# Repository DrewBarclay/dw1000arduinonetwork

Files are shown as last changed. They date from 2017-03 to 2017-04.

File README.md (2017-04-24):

# dw1000arduinonetwork
For our computer engineering capstone project. Takes a number of DW1000s hooked up to Arduinos and has them transmit their range information to each other and to serial interfaces. For use with our other projects.

Code is intended to run on an Arduino Pro Mini 3.3V. See https://github.com/thotro/arduino-dw1000 for the core code used, as well as the final report at https://github.com/DrewBarclay/ARLocationTracking for more information.

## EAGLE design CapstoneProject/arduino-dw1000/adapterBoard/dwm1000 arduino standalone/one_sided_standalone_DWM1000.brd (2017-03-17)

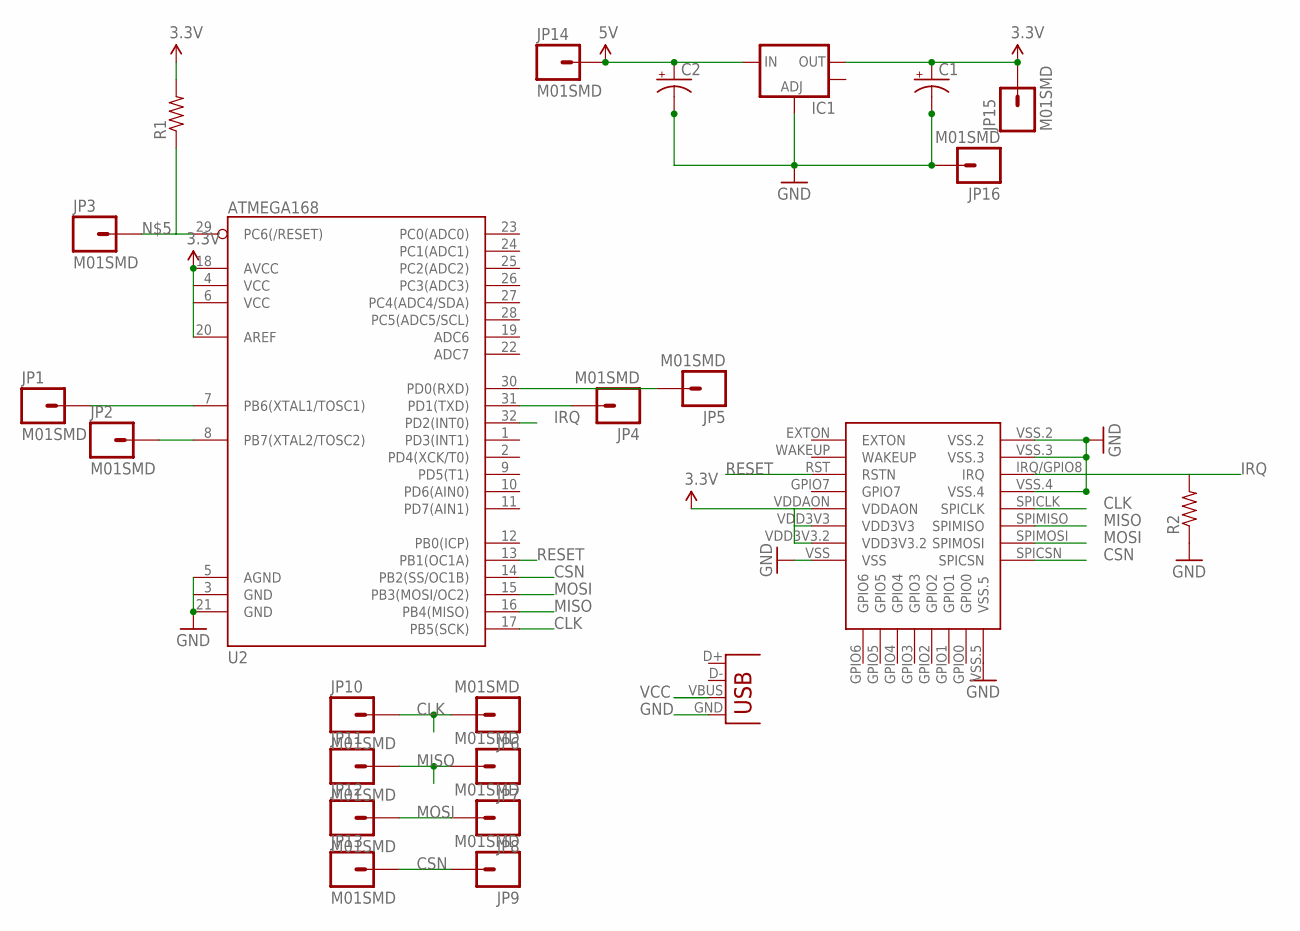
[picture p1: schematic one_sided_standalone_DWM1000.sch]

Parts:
C1, C2: CAP_POL3528-KIT; EIA3528-KIT
IC1: V_REG_LM1117SOT223; SOT223
JP1, JP2, JP3, JP4, JP5, JP6, JP7, JP8, JP9, JP10, JP11, JP12, JP13, JP14, JP15, JP16: M01SMD; LUXEON-PAD
R1, R2: RESISTOR0805-RES; 0805
U2: ATMEGA168; TQFP32-08
U$1: DWM1000
X1: USB-MICROB

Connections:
CLK: JP6.P$1, JP10.P$1, U2.17 (PB5(SCK)), U$1.SPICLK
CSN: JP9.P$1, JP13.P$1, U2.14 (PB2(SS/OC1B)), U$1.SPICSN
GND: C1.C (-), C2.C (-), IC1.1 (ADJ), JP16.P$1, R2.1, U2.3 (GND), U2.5 (AGND), U2.21 (GND), U$1.VSS, U$1.VSS.2, U$1.VSS.3, U$1.VSS.4, U$1.VSS.5, X1.GND
IRQ: R2.2, U2.32 (PD2(INT0)), U$1.IRQ/GPIO8 (IRQ)
MISO: JP7.P$1, JP11.P$1, U2.16 (PB4(MISO)), U$1.SPIMISO
MOSI: JP8.P$1, JP12.P$1, U2.15 (PB3(MOSI/OC2)), U$1.SPIMOSI
unnamed: JP1.P$1, U2.7 (PB6(XTAL1/TOSC1))
unnamed: JP2.P$1, U2.8 (PB7(XTAL2/TOSC2))
unnamed: JP3.P$1, R1.1, U2.29 (PC6(/RESET))
unnamed: JP4.P$1, U2.31 (PD1(TXD))
unnamed: JP5.P$1, U2.30 (PD0(RXD))
RESET: U2.13 (PB1(OC1A)), U$1.RST (RSTN)
VCC: C2.A (+), IC1.3 (IN), JP14.P$1, X1.VBUS
VCC3.3: C1.A (+), IC1.2 (OUT), JP15.P$1, R1.2, U2.6 (VCC), U2.18 (AVCC), U2.20 (AREF), U$1.VDD3V3, U$1.VDD3V3.2, U$1.VDDAON

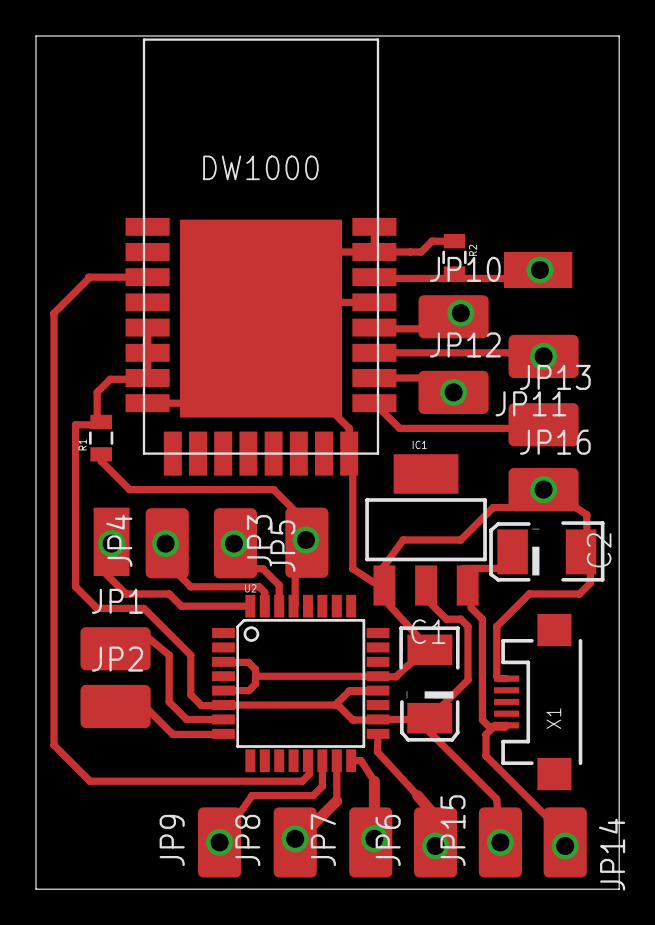
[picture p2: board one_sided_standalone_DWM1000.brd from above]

Board: 2 copper layers, 32.4 x 47.4 mm, 24 parts (0 on the bottom side), 14 nets.

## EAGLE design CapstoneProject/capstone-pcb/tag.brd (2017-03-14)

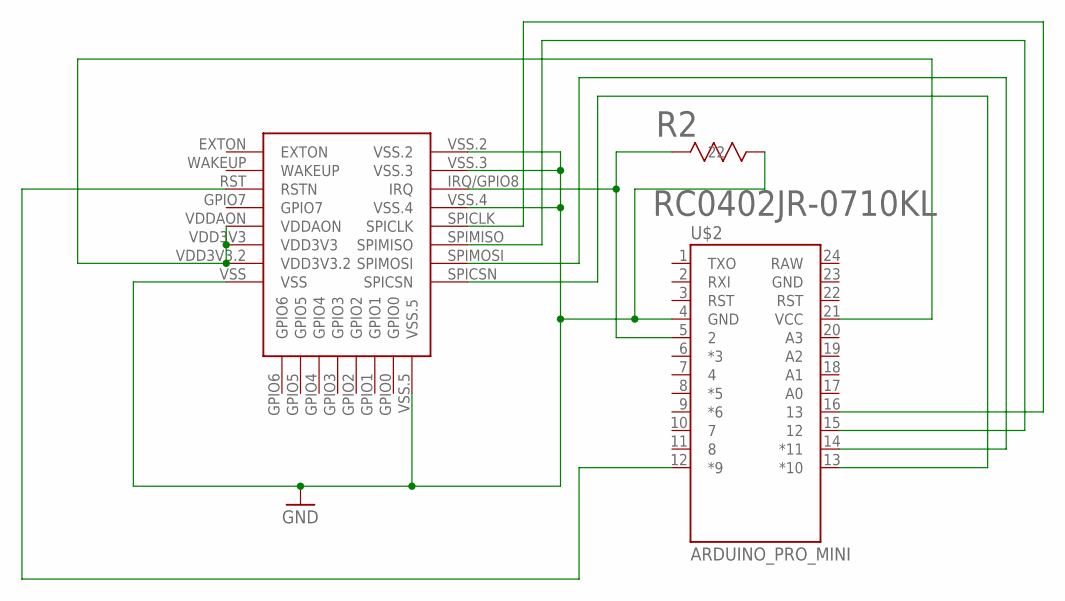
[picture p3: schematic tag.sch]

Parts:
R2: RC0402JR-0710KL; RC0402N
U$1: DWM1000
U$2: ARDUINO_PRO_MINI

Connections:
GND: R2.1 (11), U$1.VSS, U$1.VSS.2, U$1.VSS.3, U$1.VSS.4, U$1.VSS.5, U$2.4 (GND)
unnamed: U$1.VDD3V3, U$1.VDD3V3.2, U$1.VDDAON, U$2.21 (VCC)
unnamed: R2.2 (22), U$1.IRQ/GPIO8 (IRQ), U$2.5 (2)
unnamed: U$1.RST (RSTN), U$2.12 (*9)
unnamed: U$1.SPIMISO, U$2.15 (12)
unnamed: U$1.SPICLK, U$2.16 (13)
unnamed: U$1.SPIMOSI, U$2.14 (*11)
unnamed: U$1.SPICSN, U$2.13 (*10)

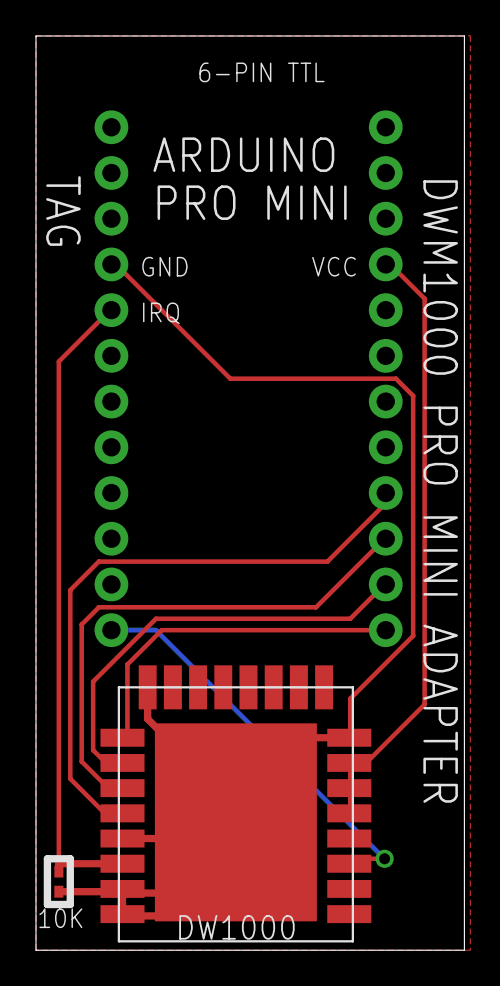
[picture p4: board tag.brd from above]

Board: 2 copper layers, 23.8 x 50.8 mm, 3 parts (0 on the bottom side), 8 nets.

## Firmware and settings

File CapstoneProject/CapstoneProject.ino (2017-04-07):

//Created by Drew Barclay
//Code uses thotro's dwm1000-arduino project
//Protocol: one byte for ID, then five bytes for the timestamp of the sending of the message, then a list of device specific stuff.
//For each device, append one byte for the ID of the device, one byte for the shared counter (used to detect lost transmissions), five bytes for timestamp of last received message from them, and four bytes for last calculated range

#include <SPI.h>
#include <DW1000.h>

class Device  {
  public:
    byte id = 0;
    byte transmissionCount;
    byte missedTransmissions = 0;
    DW1000Time timeDevicePrevSent;
    DW1000Time timePrevReceived;
    DW1000Time timeSent;
    DW1000Time timeDeviceReceived;
    DW1000Time timeDeviceSent;
    DW1000Time timeReceived;
    float lastComputedRange;
    bool hasReplied;

    Device() : lastComputedRange(0.0f), id(0), hasReplied(false) {}

    void computeRange();

    float getLastComputedRange() {
      return this->lastComputedRange;
    }
};

// CONSTANTS AND DATA START
//number of devices that can form a network at once
#define NUM_DEVICES 6
Device devices[NUM_DEVICES]; //Should be kept in order of increasing ID
int curNumDevices;
byte txOrder[NUM_DEVICES + 2]; //+2 because we include our own ID and a dummy ID here

// connection pins
const uint8_t PIN_RST = 9; // reset pin
const uint8_t PIN_IRQ = 2; // irq pin
const uint8_t PIN_SS = SS; // spi select pin

// data buffer
#define LEN_DATA 256
byte data[LEN_DATA];

//just an output buffer
String output;

//id for this device
const byte OUR_ID = 6;
const byte DUMMY_ID = 255; //for use with ending a round
#define WE_ARE_ANCHOR (OUR_ID < 5)
#define WE_ARE_TAG (OUR_ID >= 5)

unsigned long timerStart; //from millis() for use with various code needing a reference start time
unsigned long txTimerStart; //same deal for transmission round orders
unsigned long timeTransmissionOrdered = 0;

byte lastReceivedID = 0;
boolean lastReceivedWasNew = false;
byte expectedIDIdx = 0;

// delay time before sending a message, should be at least 3ms (3000us)
const unsigned int DELAY_TIME_US = 2048 + 1000 + NUM_DEVICES * 83 + 200; //should be equal to preamble symbols (each take ~1us to transmit) + 1000 (base time to communicate and start transmitting and calculating a delay timestamp) + 4.5*bytes of data to send. add a little fudge room too. (experimentally found.) in microseconds.
const unsigned long DELAY_UNTIL_ASSUMED_LOST = 4300 + 1480 + DELAY_TIME_US + 2000; //estimated max parse time + transmit time + delay time on transmit + fudge factor, the extra factor of 1200us per extra devices is added later
/* receive/transmit times and # of devices
TX   RX   #
1480 4300 2
1570 5300 3
1670 6300 4
1760 7300 5
1850 8400 6
*/


volatile bool received; //Set when we are interrupted because we have received a transmission
volatile bool sent = false; //Set when we successfully send

bool tookTurn = false;

enum state_t {START_UP, ENTERING_NETWORK, IN_THE_ROUND} state;
#define TX_ORDER_SIZE() (curNumDevices + 1 + ((state == IN_THE_ROUND) ? 1 : 0))

// CONSTANTS AND DATA END

void Device::computeRange() {
  // only call this when timestamps are correct, otherwise strangeness may result
  // asymmetric two-way ranging (more computationly intense, less error prone)
  DW1000Time round1 = (timeDeviceReceived - timeDevicePrevSent).wrap();
  DW1000Time reply1 = (timeSent - timePrevReceived).wrap();
  DW1000Time round2 = (timeReceived - timeSent).wrap();
  DW1000Time reply2 = (timeDeviceSent - timeDeviceReceived).wrap();

  DW1000Time tof = (round1 * round2 - reply1 * reply2) / (round1 + round2 + reply1 + reply2);
  float range = tof.getAsMeters();
  if (range < 1000 || range >= -10) {
    this->lastComputedRange = range;
  } else {
    this->lastComputedRange = 0;
  }
}

unsigned long max_ul(unsigned long a, unsigned long b) {
  if (a > b) {
    return a;
  } else {
    return b;
  }
}

void setup() {
  txOrder[0] = DUMMY_ID;

  received = false;
  curNumDevices = 0;
  timerStart = millis();

  Serial.begin(1000000);
  delay(1000);
  // initialize the driver
  DW1000.begin(PIN_IRQ, PIN_RST);
  DW1000.select(PIN_SS);
  Serial.println(F("DW1000 initialized ..."));
  // general configuration
  DW1000.newConfiguration();
  DW1000.setDefaults();
  DW1000.setDeviceAddress(OUR_ID);
  DW1000.setNetworkId(10);
  DW1000.enableMode(DW1000.MODE_LONGDATA_RANGE_ACCURACY);
  //const byte mode[] = {DW1000.TRX_RATE_850KBPS, DW1000.TX_PULSE_FREQ_16MHZ, DW1000.TX_PREAMBLE_LEN_512};
  //DW1000.enableMode(mode);
  if (WE_ARE_TAG) { //tag
    DW1000.commitConfiguration(16470);
  } else { //anchor
    DW1000.commitConfiguration(16500);
  }
  Serial.println(F("Committed configuration ..."));

  // attach callback for (successfully) sent and received messages
  DW1000.attachSentHandler(handleSent);
  DW1000.attachReceivedHandler(handleReceived);
  DW1000.attachErrorHandler(handleError);
  DW1000.attachReceiveFailedHandler(handleReceiveFailed);

  receiver(); //start receiving

  //!range 1 2 324.35
  //this is 17 bytes
  output.reserve((NUM_DEVICES + 1) * 17); //Allocate memory for the longest possible message that's going to be sent
}

void handleError() {
  Serial.println("Error!");
}

void handleReceiveFailed() {
  Serial.println("Receive failed!");
}

void handleSent() {
  sent = true;
}

void handleReceived() {
  received = true;
}

void receiver() {
  DW1000.newReceive();
  DW1000.setDefaults();
  // so we don't need to restart the receiver manually
  DW1000.receivePermanently(true);
  DW1000.startReceive();
}

void addIDToTxOrder(byte id) {
  //Find a place to put it in the transmission order
  int txIdx = 0;
  for (txIdx = 0; txIdx < TX_ORDER_SIZE(); txIdx++) {
    if (id < txOrder[txIdx]) {
      break;
    }
  }
  //Move everything up by 1 position to make room for this
  memmove(txOrder + txIdx + 1, txOrder + txIdx, sizeof(byte) * (TX_ORDER_SIZE() - txIdx));
  txOrder[txIdx] = id;
}

void parseReceived() {
  unsigned long parseTimer = micros();

  unsigned int len = DW1000.getDataLength();
  DW1000Time timeReceived;
  DW1000.getData(data, len);
  DW1000.getReceiveTimestamp(timeReceived);

  if (len < 6) {
    Serial.println("Received message with length <6, error.");
    return;
  }

  //Parse data
  //First byte, ID
  byte fromID = data[0];

  if (fromID == OUR_ID) {
    return; //this is an error and the send buffer has overwritten the receive buffer
  }

  lastReceivedID = fromID;

  //Second byte, 5 byte timestamp when the transmission was sent (their clock)
  DW1000Time timeDeviceSent(data + 1);

  //If this device is not in our list, add it now.
  int idx = -1;
  for (int i = 0; i < curNumDevices; i++) {
    if (devices[i].id == fromID) {
      idx = i;
    }
  }
  if (idx == -1) { //If we haven't seen this device before...
    lastReceivedWasNew = true;
    output = "";
    output += "New device found. ID: ";
    output += fromID;
    Serial.println(output);
    if (curNumDevices == NUM_DEVICES) {
      Serial.println("Max # of devices exceeded. Returning early from receive.");
      return;
    }

    addIDToTxOrder(fromID);

    //Add it to the device list
    devices[curNumDevices].id = fromID;
    devices[curNumDevices].timeDeviceSent = timeDeviceSent;
    devices[curNumDevices].transmissionCount = 1;
    devices[curNumDevices].missedTransmissions = 0;
    idx = curNumDevices;
    curNumDevices++;
  } else {
    lastReceivedWasNew = false;
  }

  devices[idx].hasReplied = true;
  devices[idx].missedTransmissions = 0;

  //Now, a list of device-specific stuff
  output = "";
  for (int i = 6; i < len;) {
    //First byte, device ID
    byte deviceID = data[i];
    i++;

    //Second byte, transmission counter
    byte transmissionCount = data[i];
    i++;

    //Next five bytes are the timestamp of when the device received our last transmit
    DW1000Time timeDeviceReceived(data + i);
    i += 5;

    //Next four bytes are a float representing the last calculated range
    float range;
    memcpy(&range, data + i, 4);
    i += 4;

    //Is this our device? If so, we have an update to do and a range to report!
    if (deviceID == OUR_ID) {
      //Mark down the two timestamps it included, as well as the time we received it
      devices[idx].timeDeviceReceived = timeDeviceReceived;
      devices[idx].timeDeviceSent = timeDeviceSent;
      devices[idx].timeReceived = timeReceived;

      //Serial.print("Transmission received from tag "); Serial.print(devices[idx].id); Serial.print(" with transmission count "); Serial.println(devices[idx].transmissionCount);

      //If everything looks good, we can compute the range!
      if (transmissionCount == 0) {
        //Error sending, reset everything.
        devices[idx].transmissionCount = 1;
      } else if (devices[idx].transmissionCount == transmissionCount) {
        if (devices[idx].transmissionCount > 1) {
          devices[idx].computeRange();
          //Serial.println(devices[idx].getLastComputedRange());
          output += "!range "; output += OUR_ID; output += " "; output += devices[idx].id; output += " "; output += devices[idx].getLastComputedRange(); output += "\n";
          //Serial.print("!range "); Serial.print(OUR_ID); Serial.print(" "); Serial.print(devices[idx].id); Serial.print(" "); Serial.println(devices[idx].getLastComputedRange());
        }
        devices[idx].transmissionCount++;
      } else {
        //Error in transmission!
        devices[idx].transmissionCount = 0;
        //Serial.println("Transmission count does not match.");
      }

      devices[idx].timeDevicePrevSent = timeDeviceSent;
      devices[idx].timePrevReceived = timeReceived;
    }

    //Serial.println(range);
    if (WE_ARE_TAG) {
      output += "!range "; output += fromID; output += " "; output += deviceID; output += " "; output += range; output += "\n";
      //Serial.print("!range "); Serial.print(fromID); Serial.print(" "); Serial.print(deviceID); Serial.print(" "); Serial.println(range);
    }
  }

  if (WE_ARE_TAG) {
    Serial.print(output);
  }

  //Serial.print("Receive time: "); Serial.println(micros() - parseTimer);
}

void doTransmit() {
  unsigned long transmitTimer = micros();

  data[0] = OUR_ID;

  //Normally we would set the timestamp for when we send here (starting at the second byte), but we'll do that later because this can take a while to calculate and we want the delay before sending to be short

  int curByte = 6;
  for (int i = 0; i < curNumDevices; i++) {
    data[curByte] = devices[i].id;
    curByte++;
    data[curByte] = devices[i].transmissionCount;
    curByte++;
    devices[i].timeReceived.getTimestamp(data + curByte); //last timestamp will contain the time we last received a transmission
    curByte += 5;
    float range = devices[i].getLastComputedRange();
    memcpy(data + curByte, &range, 4); //floats are 4 bytes
    curByte += 4;

    if (devices[i].hasReplied) {
      devices[i].transmissionCount++; //Increment for every transmission, the other device will also increment and we can check to see if they're the same to ensure the transmission was received
      devices[i].hasReplied = false; //Set to not for this round
    }
  }

  //Do the actual transmission
  DW1000.newTransmit();
  DW1000.setDefaults();

  timeTransmissionOrdered = micros();
  //Now we figure out the time to send this message!
  DW1000Time deltaTime = DW1000Time(DELAY_TIME_US, DW1000Time::MICROSECONDS);
  DW1000Time timeSent = DW1000.setDelay(deltaTime);
  timeSent.getTimestamp(data + 1); //set second byte (5 bytes will be written) to the timestamp

  DW1000.setData(data, curByte);
  DW1000.startTransmit();

  for (int i = 0; i < NUM_DEVICES; i++) {
    devices[i].timeSent = timeSent;
  }

  //Serial.print("Transmit time: "); Serial.println(micros() - transmitTimer);
}

void debug() {
  Serial.print("curNumDevices: "); Serial.print(curNumDevices);
  Serial.print(", state: "); Serial.print(state);
  Serial.print(", OUR_ID: "); Serial.print(OUR_ID);
  Serial.print(", devices[0].id: "); Serial.println(devices[0].id);
  Serial.print("Devices: ");
  for (int i = 0; i < TX_ORDER_SIZE(); i++) {
    Serial.print(txOrder[i]); Serial.print(" " );
  }
  Serial.println();
}

void checkTxOrderTime() {
  //Check timer and update if the last device was too slow
  if (micros() - txTimerStart > DELAY_UNTIL_ASSUMED_LOST + curNumDevices * 1300) {
    //Device was too slow! Note this.
    int idx = -1;
    for (int i = 0; i < curNumDevices; i++) {
      if (devices[i].id == txOrder[expectedIDIdx]) {
        idx = i;
      }
    }

    bool removed = false;
    if (idx != -1) {
      devices[idx].missedTransmissions++;
      if (devices[idx].missedTransmissions > 5) {
        removed = true;

        //Drop it!
        output = "";
        output += "!remove ";
        output += txOrder[expectedIDIdx];
        Serial.println(output);

        //First from the devices list...
        devices[idx] = devices[curNumDevices - 1];

        //And from txOrder...
        //Move everything down by 1
        memmove(txOrder + expectedIDIdx, txOrder + expectedIDIdx + 1, sizeof(byte) * (TX_ORDER_SIZE() - expectedIDIdx - 1));

        curNumDevices--;
      }
    }

    if (!removed) {
      expectedIDIdx = (expectedIDIdx + 1) % TX_ORDER_SIZE();
    } else {
      //No need to change expectedIDIdx, as we've essentially added one to it here by removing it.
    }

    txTimerStart = micros();
    tookTurn = false;
  }
}

void updateExpectedTx() {
  //Find the index
  int idx = -1;

  if (txOrder[expectedIDIdx] == lastReceivedID) {
    idx = expectedIDIdx; //optimization to avoid a lookup. while everything's operating smooth this will be the path the code takes.
  } else {
    for (int i = 0; i < TX_ORDER_SIZE(); i++) {
      if (txOrder[i] == lastReceivedID) {
        idx = i;
        break;
      }
    }
  }

  if (idx == -1) {
    Serial.println("Fatal error on expected TX index. Not found.");
    return;
  }

  expectedIDIdx = (idx + 1) % TX_ORDER_SIZE();
  tookTurn = false;
}

void loop() {
  //debug();

  if (received && !tookTurn) {
    received = false;
    unsigned long start = micros(); //This marks the beginning, since the delay used is always receive + transmit + delay time we must do this before parsing the receive
    parseReceived();
    if (!lastReceivedWasNew) {
      updateExpectedTx();
      txTimerStart = start; //Only update for non-new devices
    } else {
      expectedIDIdx = TX_ORDER_SIZE() - 1; //The new device added changes the tx order array and we should set it back to the end of the round
    }
  }

  if (sent) {
    sent = false;
    tookTurn = false;
    txTimerStart = micros(); //Other devices will receive it at this point
    if (txOrder[expectedIDIdx] == OUR_ID) {
      expectedIDIdx++; //Can be done safely because of the dummy value
    }
  }

  checkTxOrderTime();

  switch (state) {
    case START_UP:
      if (millis() - timerStart > NUM_DEVICES * 100) {
        state = ENTERING_NETWORK; //Wait a little while before transmitting so this device doesn't interfere with the rest of the network
      }
      break;
    case ENTERING_NETWORK:
      if (txOrder[expectedIDIdx] == DUMMY_ID) {
        //Round is over, we can jump in!
        doTransmit();
        addIDToTxOrder(OUR_ID);
        state = IN_THE_ROUND;
        expectedIDIdx = TX_ORDER_SIZE() - 1;
      }
      break;
    case IN_THE_ROUND:
      if (!tookTurn && OUR_ID == txOrder[expectedIDIdx]) {
        //Our turn to transmit!
        doTransmit();
        received = false; //If a signal is received before we finished the doTransmit function then there will be issues as we overwrote the received data
        //Timer is not set here; if successfully sent, it is set in the if (sent) block above. Otherwise, we will move our expected ID up when the round expires.
        tookTurn = true;
        if (WE_ARE_TAG) {
          String output = "!id ";
          output += OUR_ID;
          Serial.println(output);
        }
      }
      break;
  }
}

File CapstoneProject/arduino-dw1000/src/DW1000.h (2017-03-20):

/*
 * Copyright (c) 2015 by Thomas Trojer <thomas@trojer.net>
 * Decawave DW1000 library for arduino.
 *
 * Licensed under the Apache License, Version 2.0 (the "License");
 * you may not use this file except in compliance with the License.
 * You may obtain a copy of the License at
 *
 *     http://www.apache.org/licenses/LICENSE-2.0
 *
 * Unless required by applicable law or agreed to in writing, software
 * distributed under the License is distributed on an "AS IS" BASIS,
 * WITHOUT WARRANTIES OR CONDITIONS OF ANY KIND, either express or implied.
 * See the License for the specific language governing permissions and
 * limitations under the License.
 *
 * @file DW1000.h
 * Arduino driver library (header file) for the Decawave DW1000 UWB transceiver IC.
 * 
 * @todo
 * - impl: later:
 * - TXBOFFS in TX_FCTRL for offset buffer transmit
 * - TR in TX_FCTRL for flagging for ranging messages
 * - CANSFCS in SYS_CTRL to cancel frame check suppression
 * - HSRBP in SYS_CTRL to determine in double buffered mode from which buffer to read
 */

#ifndef _DW1000_H_INCLUDED
#define _DW1000_H_INCLUDED

#include <stdio.h>
#include <stdlib.h>
#include <string.h>
#include <Arduino.h>
#include <SPI.h>
#include "DW1000Constants.h"
#include "DW1000Time.h"

class DW1000Class {
public:
	/* ##### Init ################################################################ */
	/** 
	Initiates and starts a sessions with one or more DW1000. If rst is not set or value 0xff, a soft resets (i.e. command
	triggered) are used and it is assumed that no reset line is wired.
	 
	@param[in] irq The interrupt line/pin that connects the Arduino.
	@param[in] rst The reset line/pin for hard resets of ICs that connect to the Arduino. Value 0xff means soft reset.
	*/
	static void begin(uint8_t irq, uint8_t rst = 0xff);
	
	/** 
	Selects a specific DW1000 chip for communication. In case of a single DW1000 chip in use
	this call only needs to be done once at start up, but is still mandatory. Other than a call
	to `reselect()` this function performs an initial setup of the now-selected chip.

	@param[in] ss The chip select line/pin that connects the to-be-selected chip with the
	Arduino.
	*/
	static void select(uint8_t ss);
	
	/** 
	(Re-)selects a specific DW1000 chip for communication. In case of a single DW1000 chip in use
	this call is not needed; only a call to `select()` has to be performed once at start up. Other 
	than a call to `select()` this function does not perform an initial setup of the (again-)selected 
	chips and assumes it to have a valid configuration loaded.

	@param[in] ss The chip select line/pin that connects the to-be-selected chip with the
	Arduino.
	*/
	static void reselect(uint8_t ss);
	
	/** 
	Tells the driver library that no communication to a DW1000 will be required anymore.
	This basically just frees SPI and the previously used pins.
	*/
	static void end();
	
	/** 
	Enable debounce Clock, used to clock the LED blinking
	*/
	static void enableDebounceClock();

	/**
	Enable led blinking feature
	*/
	static void enableLedBlinking();

	/**
	Set GPIO mode
	*/
	static void setGPIOMode(uint8_t msgp, uint8_t mode);

	/**
	Resets all connected or the currently selected DW1000 chip. A hard reset of all chips
	is preferred, although a soft reset of the currently selected one is executed if no 
	reset pin has been specified (when using `begin(int)`, instead of `begin(int, int)`).
	*/
	static void reset();
	
	/** 
	Resets the currently selected DW1000 chip programmatically (via corresponding commands).
	*/
	static void softReset();
	
	/* ##### Print device id, address, etc. ###################################### */
	/** 
	Generates a String representation of the device identifier of the chip. That usually 
	are the letters "DECA" plus the	version and revision numbers of the chip.

	@param[out] msgBuffer The String buffer to be filled with printable device information.
		Provide 128 bytes, this should be sufficient.
	*/
	static void getPrintableDeviceIdentifier(char msgBuffer[]);
	
	/** 
	Generates a String representation of the extended unique identifier (EUI) of the chip.

	@param[out] msgBuffer The String buffer to be filled with printable device information.
		Provide 128 bytes, this should be sufficient.
	*/
	static void getPrintableExtendedUniqueIdentifier(char msgBuffer[]);
	
	/** 
	Generates a String representation of the short address and network identifier currently
	defined for the respective chip.

	@param[out] msgBuffer The String buffer to be filled with printable device information.
		Provide 128 bytes, this should be sufficient.
	*/
	static void getPrintableNetworkIdAndShortAddress(char msgBuffer[]);
	
	/** 
	Generates a String representation of the main operational settings of the chip. This
	includes data rate, pulse repetition frequency, preamble and channel settings.

	@param[out] msgBuffer The String buffer to be filled with printable device information.
		Provide 128 bytes, this should be sufficient.
	*/
	static void getPrintableDeviceMode(char msgBuffer[]);
	
	/* ##### Device address management, filters ################################## */
	/** 
	(Re-)set the network identifier which the selected chip should be associated with. This
	setting is important for certain MAC address filtering rules.

	@param[in] val An arbitrary numeric network identifier.
	*/
	
	
	static void setNetworkId(uint16_t val);
	
	/** 
	(Re-)set the device address (i.e. short address) for the currently selected chip. This
	setting is important for certain MAC address filtering rules.

	@param[in] val An arbitrary numeric device address.
	*/
	static void setDeviceAddress(uint16_t val);
	// TODO MAC and filters
	
	static void setEUI(char eui[]);
	static void setEUI(byte eui[]);
	
	/* ##### General device configuration ######################################## */
	/** 
	Specifies whether the DW1000 chip should, again, turn on its receiver in case that the
	last reception failed. 

	This setting is enabled as part of `setDefaults()` if the device is
	in idle mode.

	@param[in] val `true` to enable, `false` to disable receiver auto-reenable.
	*/
	static void setReceiverAutoReenable(boolean val);
	
	/** 
	Specifies the interrupt polarity of the DW1000 chip. 

	As part of `setDefaults()` if the device is in idle mode, interrupt polarity is set to 
	active high.

	@param[in] val `true` for active high interrupts, `false` for active low interrupts.
	*/
	static void setInterruptPolarity(boolean val);
	
	/** 
	Specifies whether to suppress any frame check measures while sending or receiving messages.
	If suppressed, no 2-byte checksum is appended to the message before sending and this 
	checksum is also not expected at receiver side. Note that when suppressing frame checks, 
	the error event handler	(attached via `attachReceiveErrorHandler()`) will not be triggered 
	if received data is corrupted.

	Frame checks are enabled as part of `setDefaults()` if the device is in idle mode.
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

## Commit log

2017-01-20 Fixed division by zero error?
    [CapstoneProject.ino]
2017-01-20 Attempt at a fix for computeRange crashing the system.
    [CapstoneProject.ino]
2017-02-01 Updated to use a cached range. Maybe it'll fix the bugs.
    [CapstoneProject.ino]
2017-02-01 Moved away from array of timestamps due to missed transmissions.
    [CapstoneProject.ino]
2017-02-03 Reworking project to be more robust; changing protocol to have a transmission counter.
    [CapstoneProject.ino]
2017-02-10 Hopefully fixing range bugs (as I was setting the delay outside a transmission set)
    [CapstoneProject.ino]
2017-02-10 Working version with range (had to set delay to 3ms, 1ms too small).
    [CapstoneProject.ino]
2017-02-13 Working version of the code (handles at least 5 devices; trying 7 later).
2017-03-09 Code reworked to time-share system, but it's not working well. Reworking to code to be more elegant later.
    [CapstoneProject.ino]
2017-03-14 Added EAGLE schematic.
    [tag.brd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]
2017-03-17 Modified thotro's library.
    [AdapterBoardTestBed.fzz, adapterBoard.fzz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]
2017-03-20 Latest code with calibrations and baud rate reduced.
2017-03-20 Fixed use of Serial.println causing excessive slowdown by changing to String concat.
    [CapstoneProject.ino]
2017-03-31 1 million baud rate seems to work well.
2017-04-05 Updated code to allow devices to disconnect and reconnect (devices are dropped after a number of missed transmissions). Improved efficiency of Serial.print via reserving memory in a global String.
    [CapstoneProject.ino]

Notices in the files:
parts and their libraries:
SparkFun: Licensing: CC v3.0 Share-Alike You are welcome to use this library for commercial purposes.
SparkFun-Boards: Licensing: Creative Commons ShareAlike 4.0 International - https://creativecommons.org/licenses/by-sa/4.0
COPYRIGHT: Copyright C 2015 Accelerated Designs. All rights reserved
